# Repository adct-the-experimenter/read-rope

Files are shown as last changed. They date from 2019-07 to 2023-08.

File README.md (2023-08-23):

# Read Rope 

## Moved to new location https://gitlab.com/pab44/read-rope 

This is an open-source hardware project for a device that outputs a certain voltage depending on where the rope/wire is bent.

Hackaday project: https://hackaday.io/project/166557-read-rope-electronic-nerve

Resistive Flex Sensor used: https://www.adafruit.com/product/1070

# How It Works:

A resistive flex sensor is in parallel with a limiter resistor.

The resistive flex sensor increases in resistance when bent, which increases the voltage at the output.

The limiter resistor in parallel to the resistive flex sensor scales the increase in resistance, which also scales the increase in voltage at the output.

There is a series chain of flexible sections, each containing a parallel combination of a resistive flex sensor and limiter resistor.

Different values for a limiter resistor in each section make for several equivalent resistors in series with each other
that contribute different increases in output voltage when bent depending on the limiter resistor value.

If individual limiter resistors resistance value in each section of the chain were set to make 
the limiter resistor value dependent on the distance from the output node,

then, the increase in output voltage would depend on the distance of a flexible section from the output node
thus making output voltage depend on the location of the bend of a flex resistor due to the limiter resistor's 
value depending on location of the bend.

See the diagram/schematic/figure for read rope circuit in read-rope-flex-resistor-diagram.png 
and the sample results in read-rope-sample-result-4-sections.png.

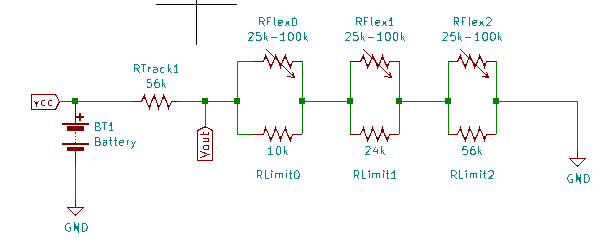
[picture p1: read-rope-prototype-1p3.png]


# Applications:
 - Control for disabled 
 - Virtual Reality/ Augmented Reality (e.g. track precise movement of finger bend, arm bend, leg bend)
 - Interactive control for video games
 - Interactive control for electronic musical instruments
 - Interactive control for training simulation

# Simulation

Have python and ngspice installed.

Run python script read-rope-flex-resistor-circuit-sim.py

    python read-rope-flex-resistor-circuit-sim.py

## Interpreting Output
  
1. Look at the Equivalent Resistance at Output vs Combination graph.
2. Determine the combination of bends you want to see.
 - 0 = no bend, 1 = bend
 - combination 1 = 01 = no bend at section 1, bend at section 0
3. Look up the equivalent resistant value at output for the combination selected in the Equivalent Output Resistance vs Combination graph.
4. Look at the Output Voltage vs Equivalent Resistance at Output graph.
5. Look up the output voltage for equivalent resistance in Output Voltage vs Equivalent Resistance at Output graph.
  
## Interpreting bend combination from output voltage.

1. Look at the Output Voltage vs Equivalent Resistance at Output graph.
2. In Output Voltage vs Equivalent Resistance at Output graph, look up the equivalent resistance for output voltage read.
3. Look at the Equivalent Resistance at Output vs Combination graph.
4. In Equivalent Resistance at Output vs Combination graph, look up the combination number for the equivalent resistant value at output.
5. Determine the combination of bends from the combination number.
	- 0 = no bend, 1 = bend
	- combination 1 = 001 = no bend at section 2,no bend at section 1, bend at section 0
	- combination 4 = 100 = bend at section 2, no bend at section 1, no bend at section 0

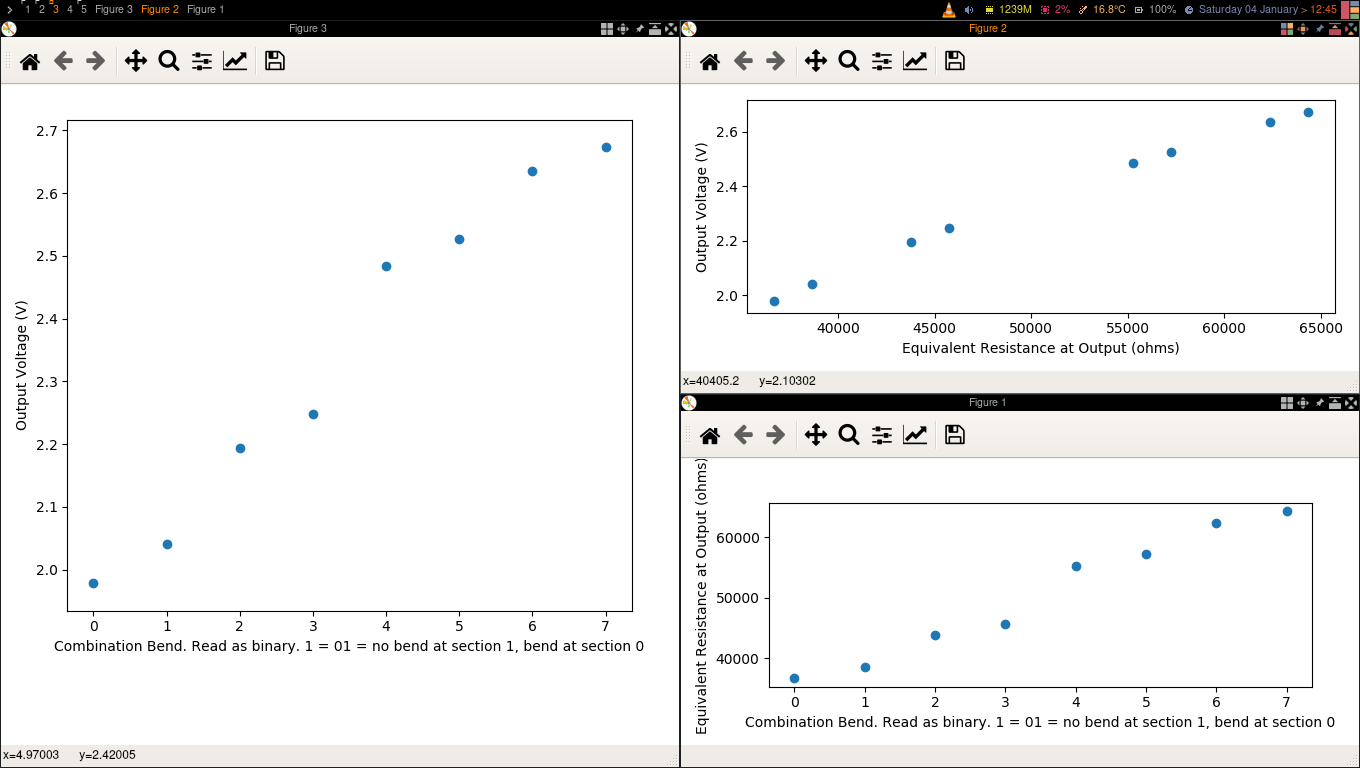
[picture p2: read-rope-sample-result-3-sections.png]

  
## Circuit

VCC-Rtrack-Req-GND
 
Vout = VCC * (Req / (Rtrack + Req))

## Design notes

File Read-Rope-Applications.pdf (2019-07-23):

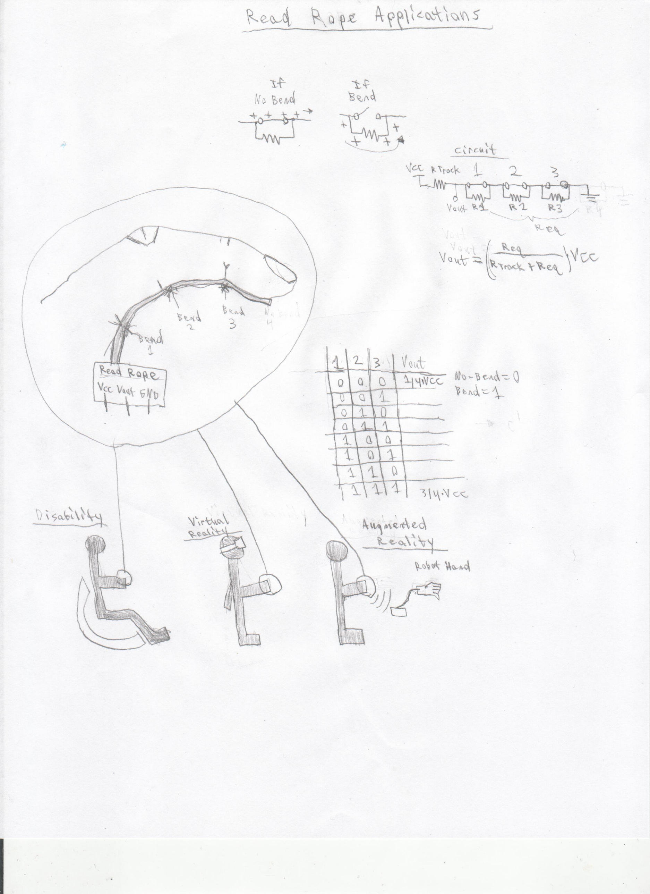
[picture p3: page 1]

_ \lJ\___c9__?J?____?_g__tt________0__nl__n?_?0__?______c7__ _______x__t_%_/ J__cg?_JJq;__t?_ttc9_c9\___@_pt_c9J \__v______ht_ga | _cG_ | _ _ | g_ | \_ o_% _" __CC_ ___ | __ | __ | ,vp ;g_ | ____ | _ _ , _? | ,a _ | 0 | _ | _ , | __ _ ____ | ,,, ,, | __ h_r___ J_ _ _ | _/ | ,, | Va__ ___ __ h3, _ | ?__ _ - -_v_n___ | V___ | '" | ` | va,_ __ , | ,_"'' | _h______e_i | ,, | _,,_ "' | ,_, | _ | '_ | '' | ," ___ | ,í | J | /' | _ _ 3 V_'__ | ____pg | í | _ " _ | N0_gg,___ , | V?_v,,t 6x, | / | ?` - g,____ | _ | C0_____ "-- | __? | ___ _ j | 1__ _ | _ | j '_ __ | _\_._ ,, _, ; $,b_,__, _ | , | , | __t_?_ | t | _ _gJt___ | ___" ,_%D, | _,,, ,, __,_; | O"__ | ,', _ | ,, | ____ __h4 | ' , ,.„,_ | G,J | _:,_`___ | _,,'' | 3xJ__,J , '_(,_,__ | _4':5 | ,_ | cv_ | J | _"CC"" | ' | '" '

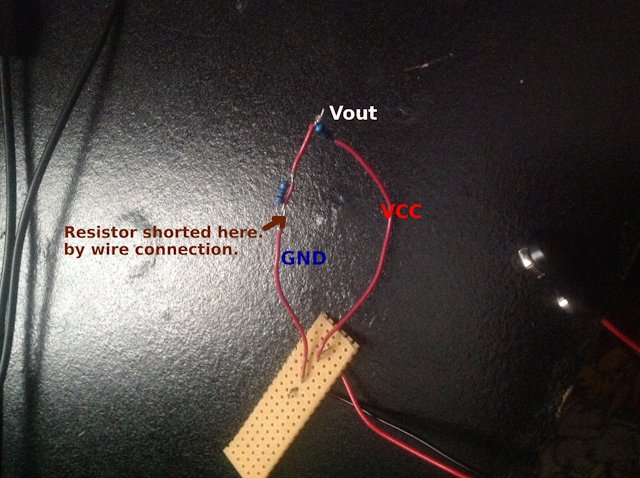
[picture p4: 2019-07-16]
proof-of-concept-wire-short-resistor.JPG

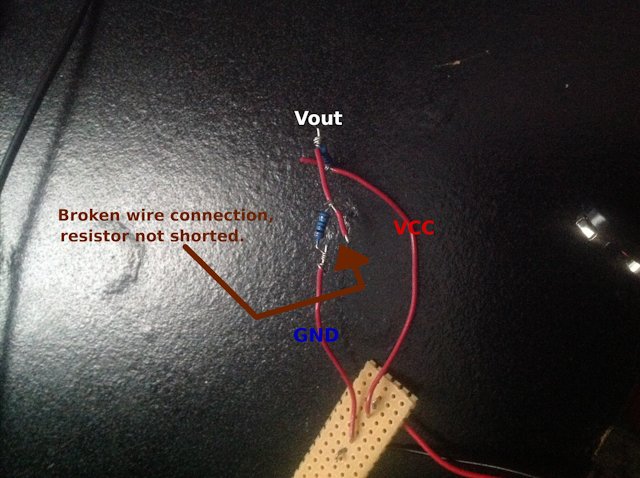
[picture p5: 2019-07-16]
proof-of-concept-broken-connection-resistance-added.JPG

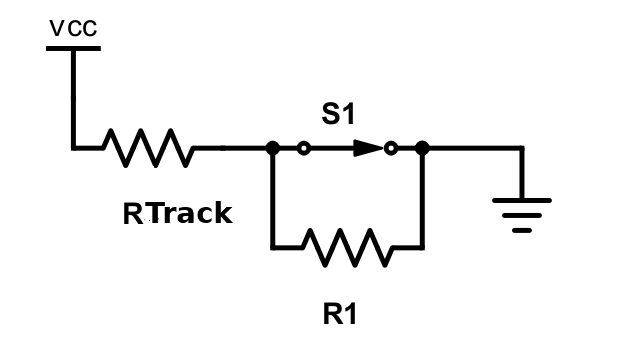
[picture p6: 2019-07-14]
read-rope-diagram-1-bend.png

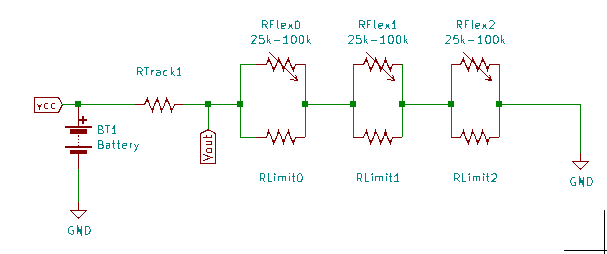
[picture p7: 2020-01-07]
read-rope-3-section-diagram.png

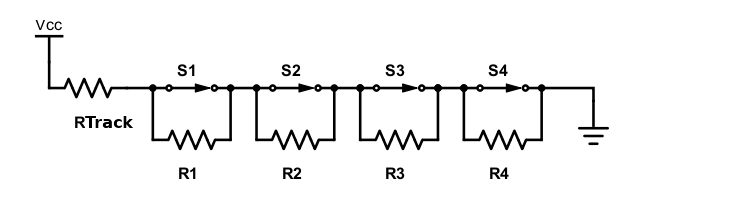
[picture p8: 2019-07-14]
read-rope-diagram-4-bends.png

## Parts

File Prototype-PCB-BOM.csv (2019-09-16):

Designator | Part Ref. Number | Designation | Quantity | Unit Cost | Unit Prototype Cost | 5 Prototype Cost | URL | 5x Flex PCB | Total Cost 5 Prototype
R1,RTRACK1 | KTR18EZPF3004 | 3Meg | 2 | $0.20 | $0.40 | $2.00 | https://www.mouser.com/ProductDetail/ROHM-Semiconductor/KTR18EZPF3004 | $124.35 | $142.15
R2 | KTR18EZPF2004 | 2Meg | 1 | $0.20 | $0.20 | $1.00 | https://www.mouser.com/ProductDetail/ROHM-Semiconductor/KTR18EZPF2004
R3 | KTR18EZPF1004 | 1Meg | 1 | $0.20 | $0.20 | $1.00 | https://www.mouser.com/ProductDetail/ROHM-Semiconductor/KTR18EZPF1004
R4 | KTR18EZPF7503 | 750k | 1 | $0.20 | $0.20 | $1.00 | https://www.mouser.com/ProductDetail/ROHM-Semiconductor/KTR18EZPF7503
SW1,SW2,SW3,SW4 | KSR221GNCLFS-SMT-NCSPST | SW_SPST | 4 | $0.64 | $2.56 | $12.80 | https://www.digikey.com/product-detail/en/KSR221GNCLFS/CKN12171CT-ND/9655821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

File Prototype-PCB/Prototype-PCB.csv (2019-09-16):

Designator | Package | Quantity | Designation | Supplier and ref
R1,RTRACK1 | KTR18EZPF3004 | 2 | 3Meg
R2 | KTR18EZPF2004 | 1 | 2Meg
R3 | KTR18EZPF1004 | 1 | 1Meg
R4 | KTR18EZPF7503 | 1 | 750k
SW1,SW2,SW3,SW4 | KSR221GNCLFS-SMT-NCSPST | 4 | SW_SPST

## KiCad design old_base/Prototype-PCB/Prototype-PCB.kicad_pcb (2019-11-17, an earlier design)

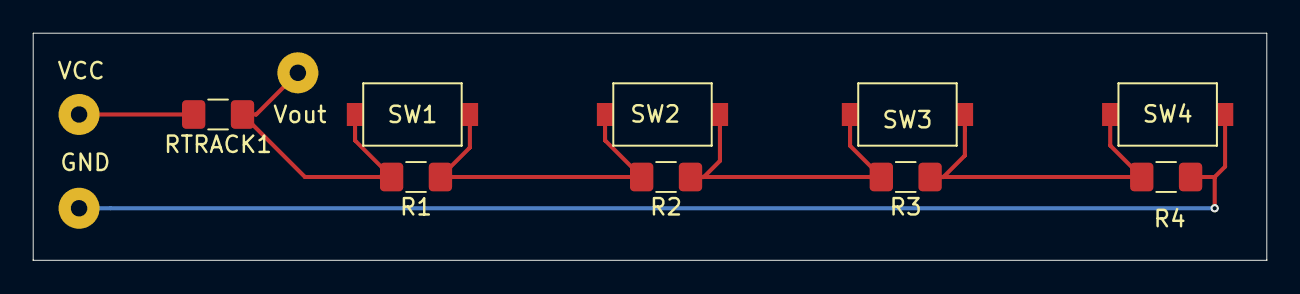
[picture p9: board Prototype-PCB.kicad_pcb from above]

Board: 2 copper layers, 75.2 x 13.8 mm, 12 parts (0 on the bottom side), 6 nets.

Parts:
GND: SolderWirePad_1x01_Drill1mm
R1: 9k; R_1206_3216Metric_Pad1.42x1.75mm_HandSolder
R2: 7k; R_1206_3216Metric_Pad1.42x1.75mm_HandSolder
R3: 3k; R_1206_3216Metric_Pad1.42x1.75mm_HandSolder
R4: 1k; R_1206_3216Metric_Pad1.42x1.75mm_HandSolder
RTRACK1: 20k; R_1206_3216Metric_Pad1.42x1.75mm_HandSolder
SW1, SW2, SW3, SW4: SW_SPST; KSR221GNCLFS-SMT-NCSPST
VCC: SolderWirePad_1x01_Drill1mm
Vout: SolderWirePad_1x01_Drill1mm

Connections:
GND: GND.1, R4.1, SW4.2
unnamed: R1.1, R2.2, SW1.2, SW2.1
unnamed: R2.1, R3.2, SW2.2, SW3.1
unnamed: R3.1, R4.2, SW3.2, SW4.1
VCC: RTRACK1.2, VCC.1
vout: R1.2, RTRACK1.1, SW1.1, Vout.1

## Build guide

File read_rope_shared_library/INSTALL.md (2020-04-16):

#How to build the library

1. $ mkdir build
2. $ cd build
3. $ cmake ..
4. $ make

#How to install the library system-wide

sudo make install

default location is in /usr/local/lib

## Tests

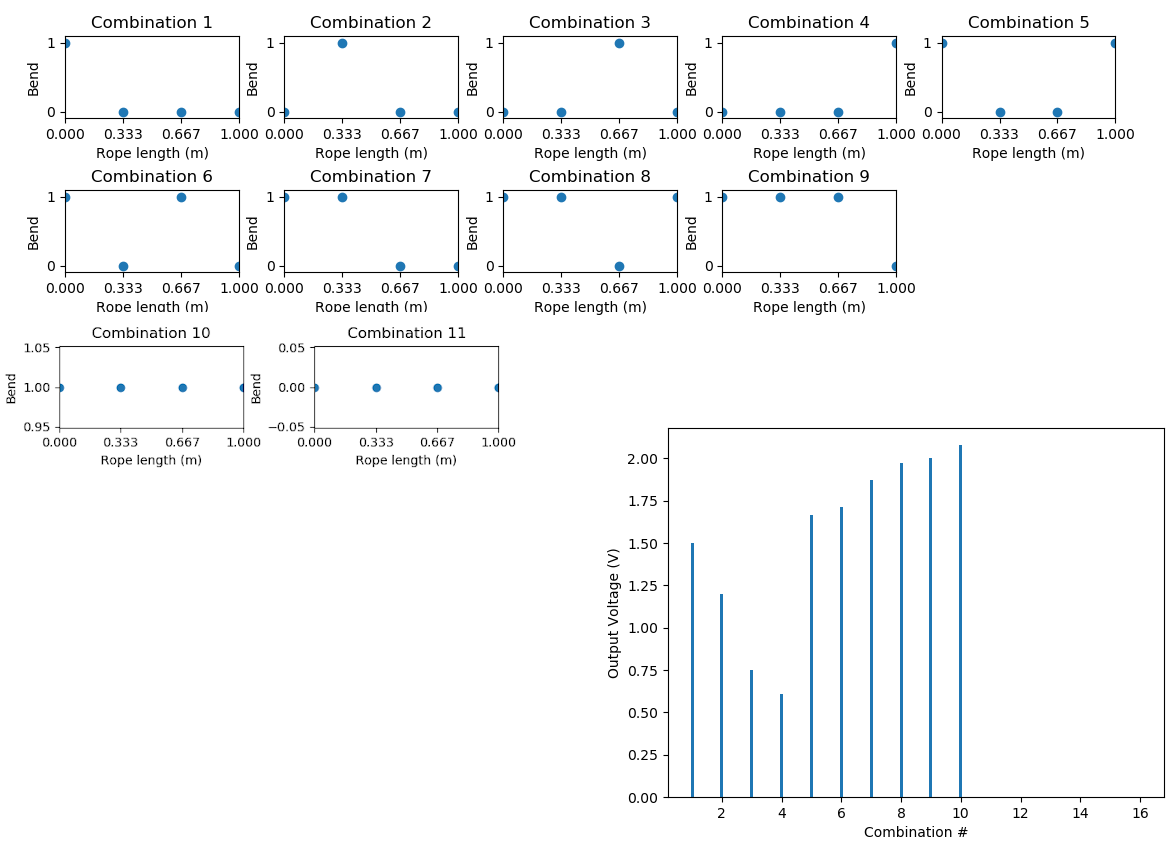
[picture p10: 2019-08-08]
read-rope-sim-results.png

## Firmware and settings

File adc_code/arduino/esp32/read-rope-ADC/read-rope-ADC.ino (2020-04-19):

//Arduino Code for reading ADC from read rope
//for esp32

/*

  For the current prototype, 3 bend section.
  VCC - 56k -|- 10k - 24k - 56k - GND
            Out 
 0 = no bend, 1 = bend

 Arduino Uno has 10-bit ADC taking in values from 0V - 5V, 4.9mV per unit
 https://www.arduino.cc/reference/en/language/functions/analog-io/analogread/

 Pins Used:
 5V, GND, A0

 Set Serial Monitor to 9600 baud rate.
 
 Combination | Bends  |  Expected Output Voltage  |  ADC value

 0              000              1.978                  403
 1              001              2.041                  416
 2              010              2.194                  447
 3              011              2.248                  458
 4              100              2.484                  506
 5              101              2.527                  515
 6              110              2.635                  537
 7              111              2.673                  545
 
 */

//GPIO pin declarations
#define ANALOG_PIN_0 36 //pin VP in ESP32 Devkit C V4 

void setup() 
{
  // put your setup code here, to run once

  
  // initialize serial communication at 9600 baud rate
  Serial.begin(9600);

}

void loop() 
{
  // put your main code here, to run repeatedly:

  //read serial input to determine which state to run
  ReadSerialForStateInput();

  delay(100);
}

void ReadSerialForStateInput()
{
  
  if (Serial.available() > 0) 
  {
    char incomingCharacter = Serial.read();
    
    switch (incomingCharacter) 
    {
 
      // send ADC value to serial
      case '$':
      {
        SendADCValueToSerial();
        break;
      }
      //send character Y to serial
      case '%':
      {
        Serial.println("Y");
        break;
      }
    }
  }

  
}

void SendADCValueToSerial()
{
	uint16_t ADC_value = analogRead(ANALOG_PIN_0);
	Serial.println(ADC_value);
}

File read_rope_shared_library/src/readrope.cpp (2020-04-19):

#include "readrope.h"



#include <cstdio>

/**
 * Determination a platform of an operation system
 * Fully supported supported only GNU GCC/G++, partially on Clang/LLVM
 */

#if defined(_WIN32)
    #define PLATFORM_NAME "windows" // Windows
#elif defined(_WIN64)
    #define PLATFORM_NAME "windows" // Windows
#elif defined(__CYGWIN__) && !defined(_WIN32)
    #define PLATFORM_NAME "windows" // Windows (Cygwin POSIX under Microsoft Window)
#elif defined(__ANDROID__)
    #define PLATFORM_NAME "android" // Android (implies Linux, so it must come first)
#elif defined(__linux__)
    #define PLATFORM_NAME "linux" // Debian, Ubuntu, Gentoo, Fedora, openSUSE, RedHat, Centos and other
#elif defined(__unix__) || !defined(__APPLE__) && defined(__MACH__)
    #include <sys/param.h>
    #if defined(BSD)
        #define PLATFORM_NAME "bsd" // FreeBSD, NetBSD, OpenBSD, DragonFly BSD
    #endif
#elif defined(__hpux)
    #define PLATFORM_NAME "hp-ux" // HP-UX
#elif defined(_AIX)
    #define PLATFORM_NAME "aix" // IBM AIX
#elif defined(__APPLE__) && defined(__MACH__) // Apple OSX and iOS (Darwin)
    #include <TargetConditionals.h>
    #if TARGET_IPHONE_SIMULATOR == 1
        #define PLATFORM_NAME "ios" // Apple iOS
    #elif TARGET_OS_IPHONE == 1
        #define PLATFORM_NAME "ios" // Apple iOS
    #elif TARGET_OS_MAC == 1
        #define PLATFORM_NAME "osx" // Apple OSX
    #endif
#elif defined(__sun) && defined(__SVR4)
    #define PLATFORM_NAME "solaris" // Oracle Solaris, Open Indiana
#else
    #define PLATFORM_NAME NULL
#endif

// Return a name of platform, if determined, otherwise - an empty string
const char *get_platform_name() 
{
    return (PLATFORM_NAME == NULL) ? "" : PLATFORM_NAME;
}

//system refers to the state machine and functions performed by the read rope library. 



uint16_t LIMIT_ZERO = 0;
uint16_t LIMIT_ONE = 0;
uint16_t LIMIT_TWO = 0;
uint16_t LIMIT_THREE = 0;
uint16_t LIMIT_FOUR = 0;
uint16_t LIMIT_FIVE = 0;
uint16_t LIMIT_SIX = 0;
uint16_t LIMIT_SEVEN = 0;


enum class State : uint8_t {
							STATE_NULL=0, 
							STATE_CALIBRATION_START, 
							STATE_CALIBRATION_S0, 
							STATE_CALIBRATION_S1, 
							STATE_CALIBRATION_S2,
							STATE_READ
							};

//state machine of the system
State state_machine;

//serial device communicator
SimpleSerial* m_serial_dev_ptr;

bool systemInitialized = false;

void ReadRope::InitReadRopeSystem()
{
	state_machine = State::STATE_NULL;	
	
	m_serial_dev_ptr = nullptr;
	
	systemInitialized = true;
}

void ReadRope::CloseReadRopeSystem()
{
	state_machine = State::STATE_NULL;
	
	if(m_serial_dev_ptr)
	{
		delete m_serial_dev_ptr;
	}
	
	m_serial_dev_ptr = nullptr;
}

std::string ReadRope::GetSerialPortOfReadRopeDevice()
{
	std::string platform_str(get_platform_name());
	
	//std::cout << "Platform:" << platform_str << std::endl;
	
	std::string port = "Null";
	std::string temp_port;
	
	std::string interface_str = "";
	
	if(platform_str == "linux")
	{
		//get available serial ports 
		//for now just do expected serial port names /dev/ttyACMX X = 0-4 and /dev/ttyUSBX
		
		bool stopTrying = false;
		
		interface_str = "/dev/ttyACM";
		
		int count = 0;
		
		while(!stopTrying)
		{
			
			
			for(int i = 0; i < 4; i++)
			{
				//bool to indicate if should continue to testing if device is read rope
				bool continueToIdentification = false;
				
				//try connecting to serial port
				try
				{
					temp_port = interface_str + std::to_string(i);
					std::cout << "testing port " << temp_port << std::endl;
					
					SimpleSerial tempSerialDevice(temp_port,9600);
					continueToIdentification = true;
				}
				catch(boost::system::system_error& e)
				{
					std::cout<< "Error: " << e.what() << std::endl;
					continueToIdentification = false;
				}
				
				//if should test if device is read rope
				if(continueToIdentification)
				{
					std::cout << "sending ID to device on this port... \n"; 
					
					SimpleSerial tempSerialDevice(temp_port,9600);
					
					//send specific serial character sequence
					tempSerialDevice.writeString("%");
					
					std::cout << "Sent ID %.\n";
					
					std::string response = tempSerialDevice.readLine();
					std::cout << "response: " << response << std::endl;
					
					//read answer
					if(response == "Y")
					{
						std::cout << "Read rope is in port " << temp_port << std::endl;
						port = temp_port;
						//stop for loop
						break;
					}
					else
					{
						std::cout << "This is not a read rope device\n";
					}
				}
				
			}
			
			if(port != "Null"){stopTrying = true;}
			
			interface_str = "/dev/ttyUSB";
			count++;
			
			if(count == 2){stopTrying = true;}
			
		}
		
		
	}
	else if(platform_str == "windows")
	{
		//To be implemented
		//list available serial ports
	}
	
	return port;
}

ReadRope::Status ReadRope::InitSerialCommunication(std::string port,unsigned int baud_rate)
{
	if(!systemInitialized)
	{
		return ReadRope::Status::ERROR_SYS_NOT_INIT;
	}
	
	try
	{
		m_serial_dev_ptr = new SimpleSerial(port,baud_rate);
		std::cout << "Successfully established communication with serial device read rope. \n";
	}
	catch(boost::system::system_error& e)
	{
		std::cout<< "Error: " << e.what() << std::endl;
		delete m_serial_dev_ptr;
		m_serial_dev_ptr = nullptr;
		
		return ReadRope::Status::ERROR;
	}
	
	return ReadRope::Status::SUCCESS;
}

#include <time.h>

static bool hasTimeLimitPassed(time_t& start, double& duration)
{
	double seconds_since_start = difftime( time(0), start);

	if(seconds_since_start > duration){return true;}
	
	return false;
}

void ReadRope::CalibrateSectionZeroMaxLimit(double& duration)
{
	bool stopCalibration = false;
  
	//get start time
	time_t start = time(0);

	while(!stopCalibration)
	{
		// Read the analog value from read rope device
		uint16_t ADC_value = ReadRope::GetADCValueOfReadRope();

		if(ADC_value > LIMIT_ONE && ADC_value > LIMIT_ZERO)
		{
			ReadRope::SetSectionZeroMaxLimit(ADC_value);
		}
		
		stopCalibration = hasTimeLimitPassed(start,duration);

	}
  
}

void ReadRope::SetSectionZeroMaxLimit(uint16_t& limit){LIMIT_ONE = limit;}

void ReadRope::CalibrateSectionOneMaxLimit(double& duration)
{
	bool stopCalibration = false;
  
	//get start time
	time_t start = time(0);
  
	while(!stopCalibration)
	{
		// Read the analog value from pin A0
		uint16_t ADC_value = ReadRope::GetADCValueOfReadRope();

		if(ADC_value > LIMIT_TWO && ADC_value > LIMIT_ONE)
		{
			ReadRope::SetSectionOneMaxLimit(ADC_value);
		}

		stopCalibration = hasTimeLimitPassed(start,duration);
	}

}

void ReadRope::SetSectionOneMaxLimit(uint16_t& limit){LIMIT_TWO = limit;}
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

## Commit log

2019-07-14 Added visual schematic/diagrams to make it easier to understand how the hardware works.
2019-07-16 Added images of proof of concept prototype.
2019-07-20 Added simulation for the 4 bend read rope physical prototype that will be made.
2019-07-23 Updated comments in read-rope-4-bend-prototype-sim.py file
2019-08-08 Added kicad schematic and kicad project file for flexible pcb design.
    [Prototype-PCB.kicad_pcb, Prototype-PCB.sch]
2019-08-15 Started pcb with associated footprints for components.
2019-08-15 Made pcb prototype with vias connecting SMD components on both sides.
    [Prototype-PCB.sch]
2019-08-20 Made some gerber files and put a pad in pcb for ground connection.
    [Prototype-PCB-B_Cu.gbr, Prototype-PCB-B_Mask.gbr, Prototype-PCB-B_Paste.gbr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]
2019-09-16 Added LTSpice simulation with load resistor included.
    [Prototype-PCB-BOM.csv, Prototype-PCB.csv]
2019-09-16 Modified read-rope-4-bend-prototype to include a load resistor into the calculations.
2019-11-10 Updated ltspice simulation and changed resistor values to get a 10k ohm output impedance to have device be used with microcontroller.
    [Prototype-PCB-B_Cu.gbr, Prototype-PCB-B_Mask.gbr, Prototype-PCB-B_Paste.gbr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]
2019-11-17 Modified the pcb file. Changed the footprints for SMT resistors.
    [Prototype-PCB-B_Adhes.gbr, Prototype-PCB-B_CrtYd.gbr, Prototype-PCB-B_Cu.gbr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]
2019-11-17 Updated gerber.zip file.
2019-11-17 Fixed a mistake. Added a through-hole pad to connect output.
    [Prototype-PCB-B_Adhes.gbr, Prototype-PCB-B_CrtYd.gbr, Prototype-PCB-B_Cu.gbr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]
2019-12-24 Moved files based on older first concepts about how read rope worked to old_base directory.
    [Prototype-PCB-BOM.csv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]
2019-12-24 Removed copies of files.
    [Prototype-PCB-BOM.csv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]
2019-12-24 Added a python script to later implement a circuit simulation using ngpsice.
2019-12-24 Added circuit creation and ngspice circuit simulation run to python file.
2019-12-26 Added capability to make a read rope with any number of flexible sections as long as limiter resistors are manually defined for each section.
2019-12-26 Updated README.md to include flex sensor explanation.
2019-12-27 Added circuit diagram for use of resistive flex sensor.
2019-12-27 Changed bend and flat resistance values of resisitive flex sensor to reflect actual sensor.
2019-12-28 Added picture of sample results.
2020-01-03 Made track resistor which is the resistor between power supply and output of volt divider variable.
2020-01-03 Added plot that shows output voltage vs combination bend.
2020-01-03 Made source voltage vcc variable.
2020-01-03 Replaced picture of sample results.
2020-01-04 Added arduino ADC code. Included hackaday project link.
2020-01-04 Changed pictures and diagram to match current 3 section prototype made.
2020-01-04 Added picture for prototype version 1.3 of read rope.
2020-01-24 Programmed arduino to calibrate and read bends based on UART serial communications.
2020-04-13 Added some code for a library to abstract reading from read rope device.
2020-04-18 Fixedadc code compile errors.
    [read-rope-ADC.ino]
2020-04-18 Made comments in Arduino ADC code.
2020-04-19 Changed firmware in Arduino prototype. Removed calibration and state machine code to only have read rope device send ADC value.
2020-04-19 Changed arduino firmware. Added more to library.
2020-04-19 Completed linux UART USB serial communication in library.
2020-04-19 Added calibration functionality to the board.
2020-04-19 Implemented calibration in test. Changed calibration method.
